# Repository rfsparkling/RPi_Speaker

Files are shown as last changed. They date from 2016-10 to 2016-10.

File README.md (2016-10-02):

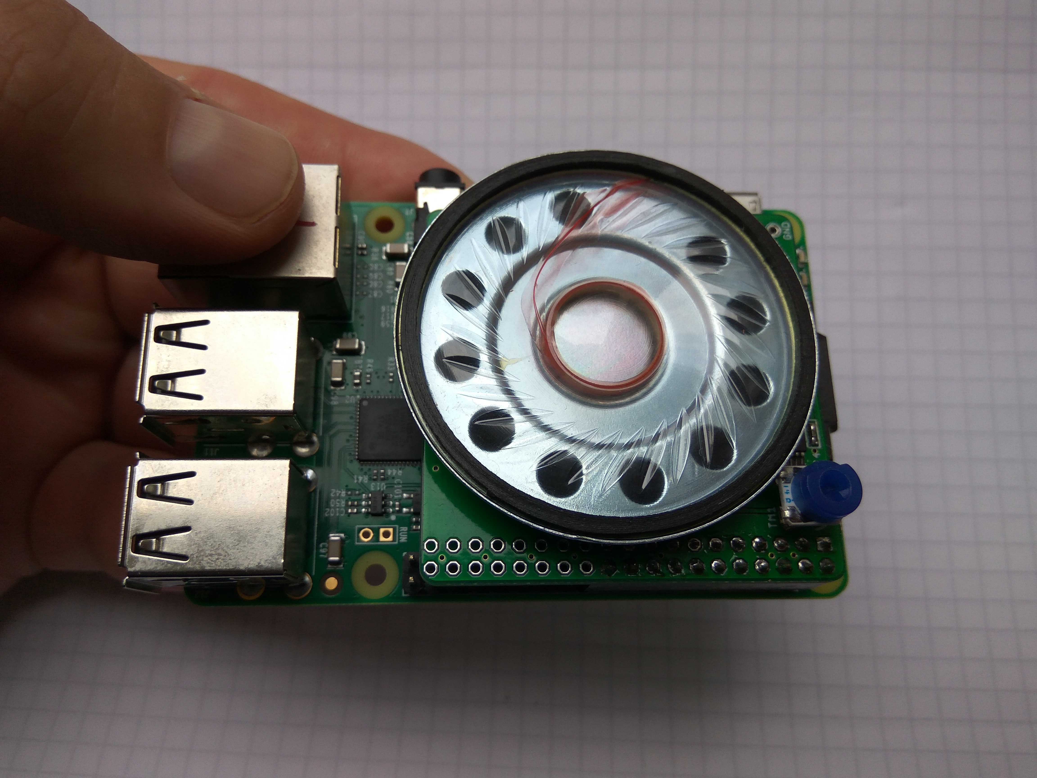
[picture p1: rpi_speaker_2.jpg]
Photo of RPi Speaker

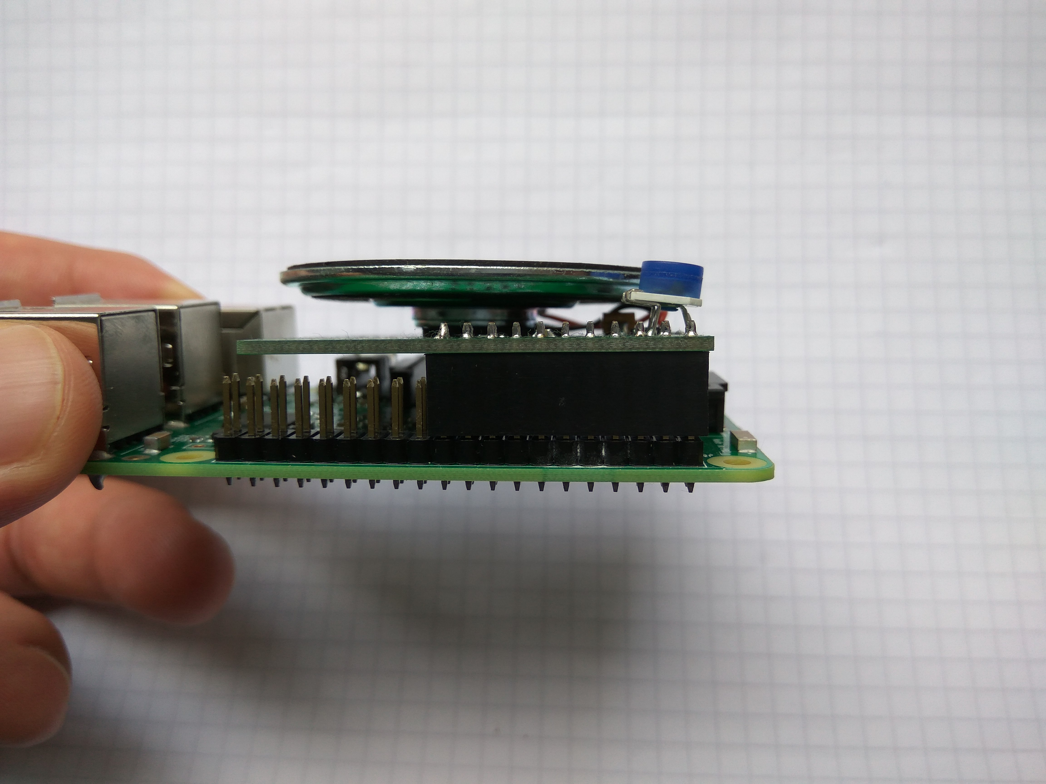
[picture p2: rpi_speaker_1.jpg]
Photo of RPi Speaker


Integrated active amplifier PCB for Rapsberry Pi (versions 1,2 and 3). On board LM386 amplifier do the amplification of the weak PWM audio signal coming out of RPi GPIO.
Also an on board low pass filter helps reconsturging the analog audio signal from PWM. 

Amplifier board built, find test video on Youtube here: http://bit.ly/rpi_speaker

------------
Installation
------------

Latest Raspbian OS has Pigpio software pre-installed, this handles GPIO alternative function. 
So just strart it and configure GPIO18 into ALT5 mode in RPi 2 and 3 (routing audio PWM signal to amplifier PCB):
In RPi 1 PWM audio can acces at GPIO12 port, see schematic.

Commands:

```
sudo pigpiod # start daemon
pigs m 18 5 # set GPIO18 to mode ALT5, RPi 2 and RPi 3 
```

Playing music with for example omxplayer (included in Raspbian) take care to route audio signal to PWM port and not HDMI output (-o local switch below).
You can listen internet stream or offline audio files. This example starts a music station:

```
omxplayer -o local http://bbcmedia.ic.llnwd.net/stream/bbcmedia_6music_mf_p
```

-----------------------
Alternative GPIO config
-----------------------

If Pigpio doesn't work for you, try this method:

https://www.raspberrypi.org/forums/viewtopic.php?f=44&t=39138

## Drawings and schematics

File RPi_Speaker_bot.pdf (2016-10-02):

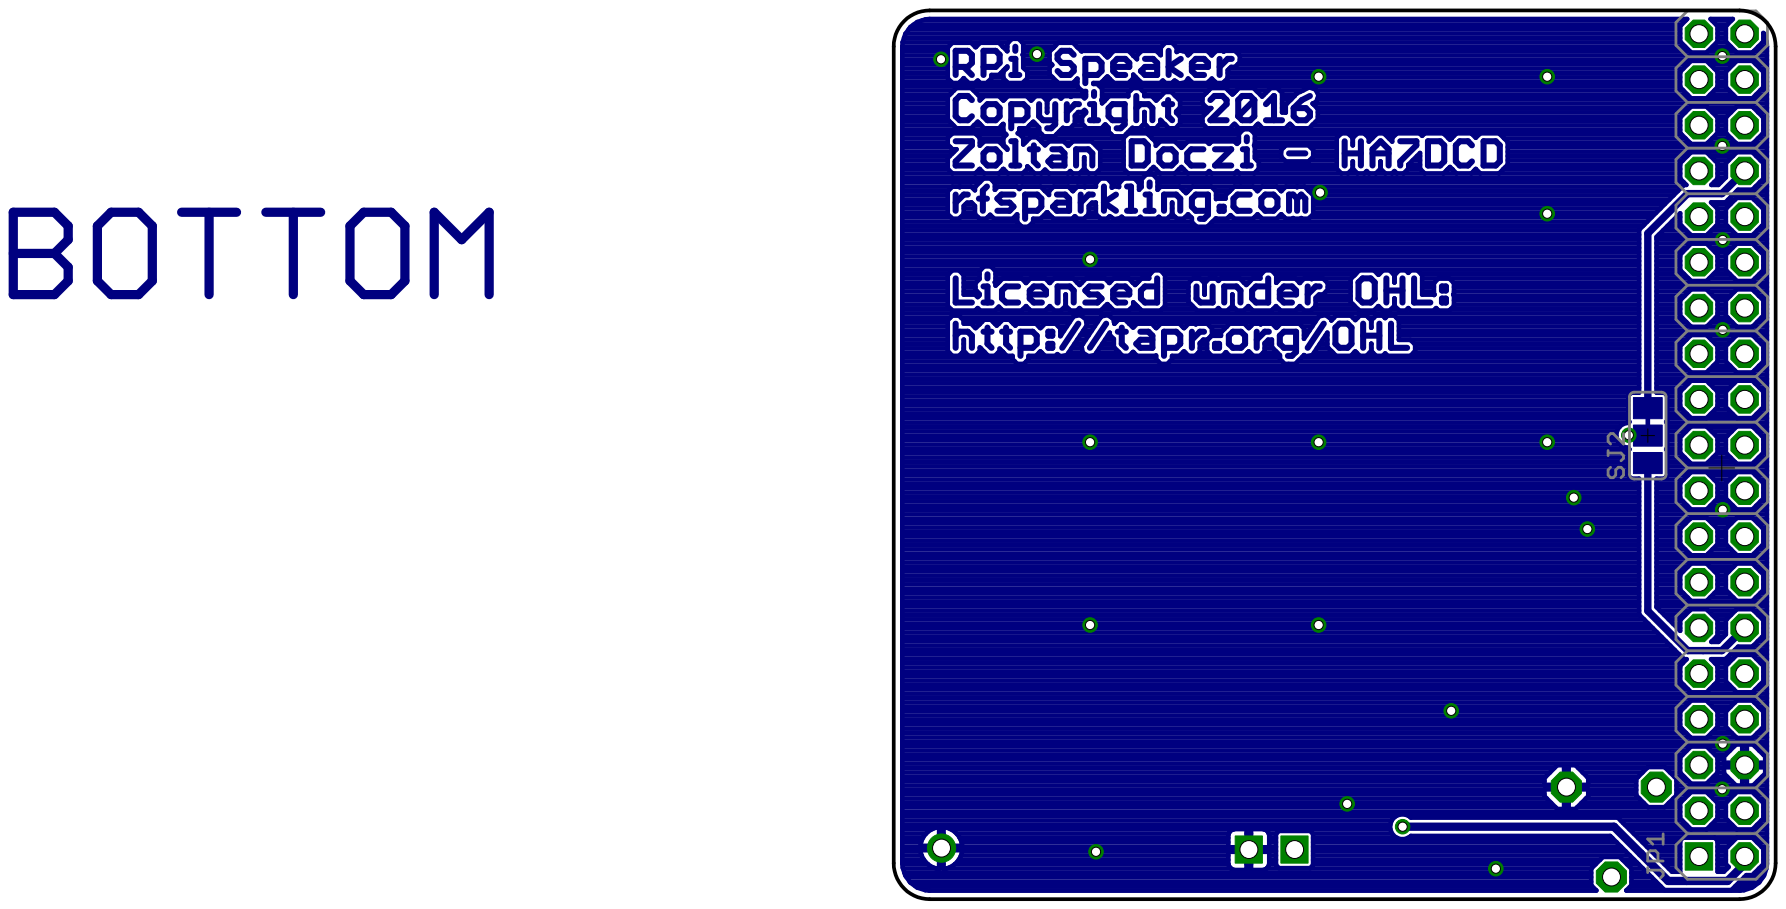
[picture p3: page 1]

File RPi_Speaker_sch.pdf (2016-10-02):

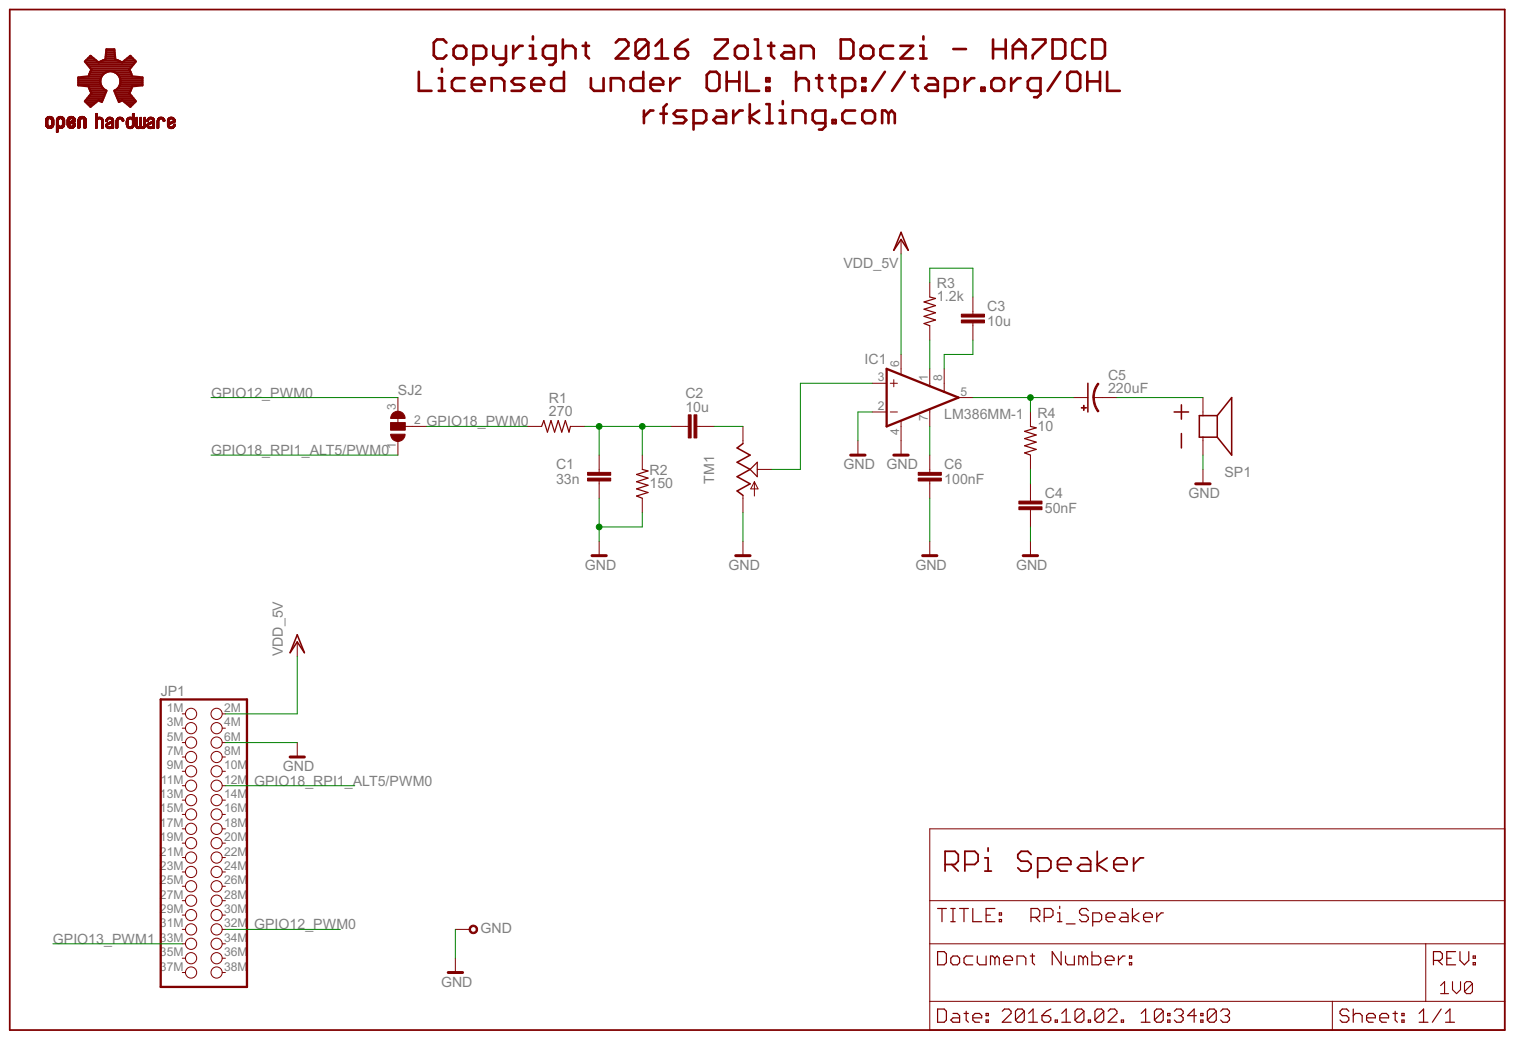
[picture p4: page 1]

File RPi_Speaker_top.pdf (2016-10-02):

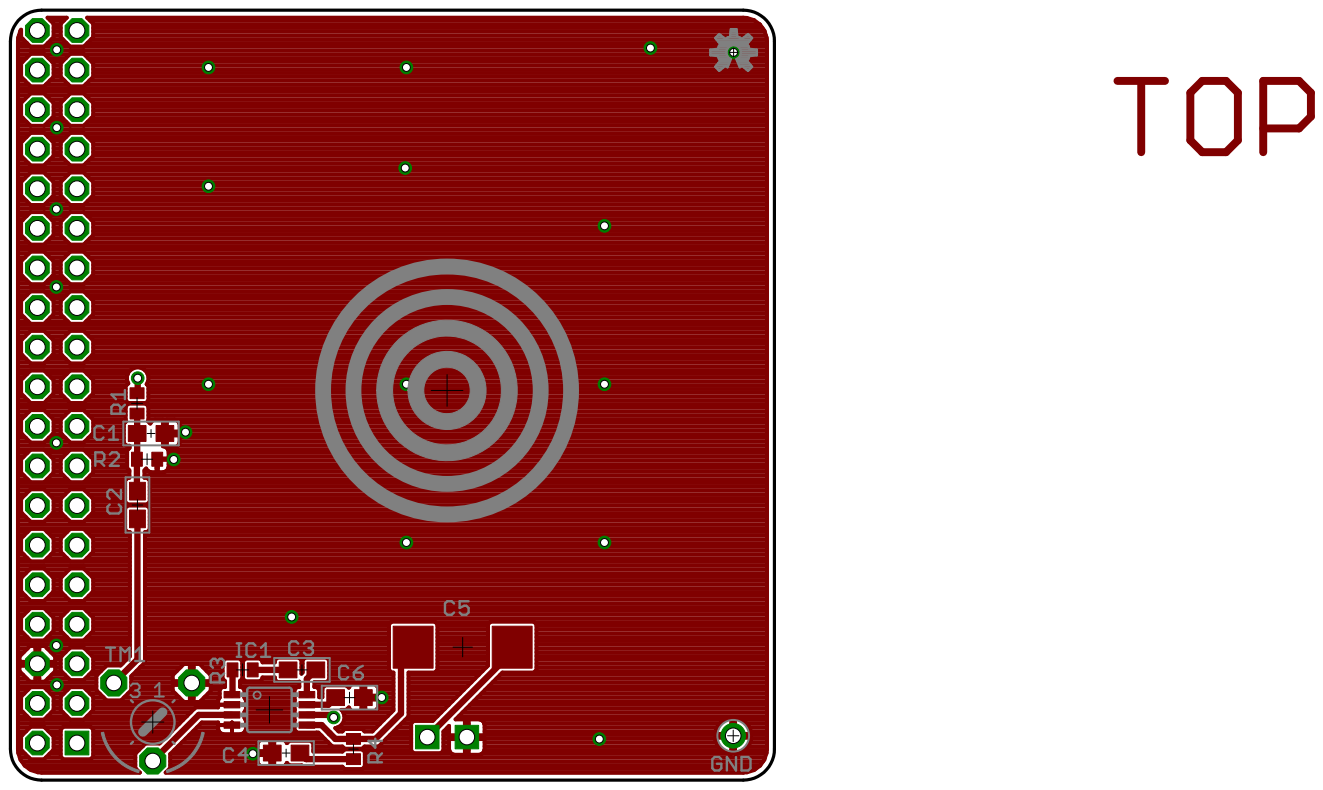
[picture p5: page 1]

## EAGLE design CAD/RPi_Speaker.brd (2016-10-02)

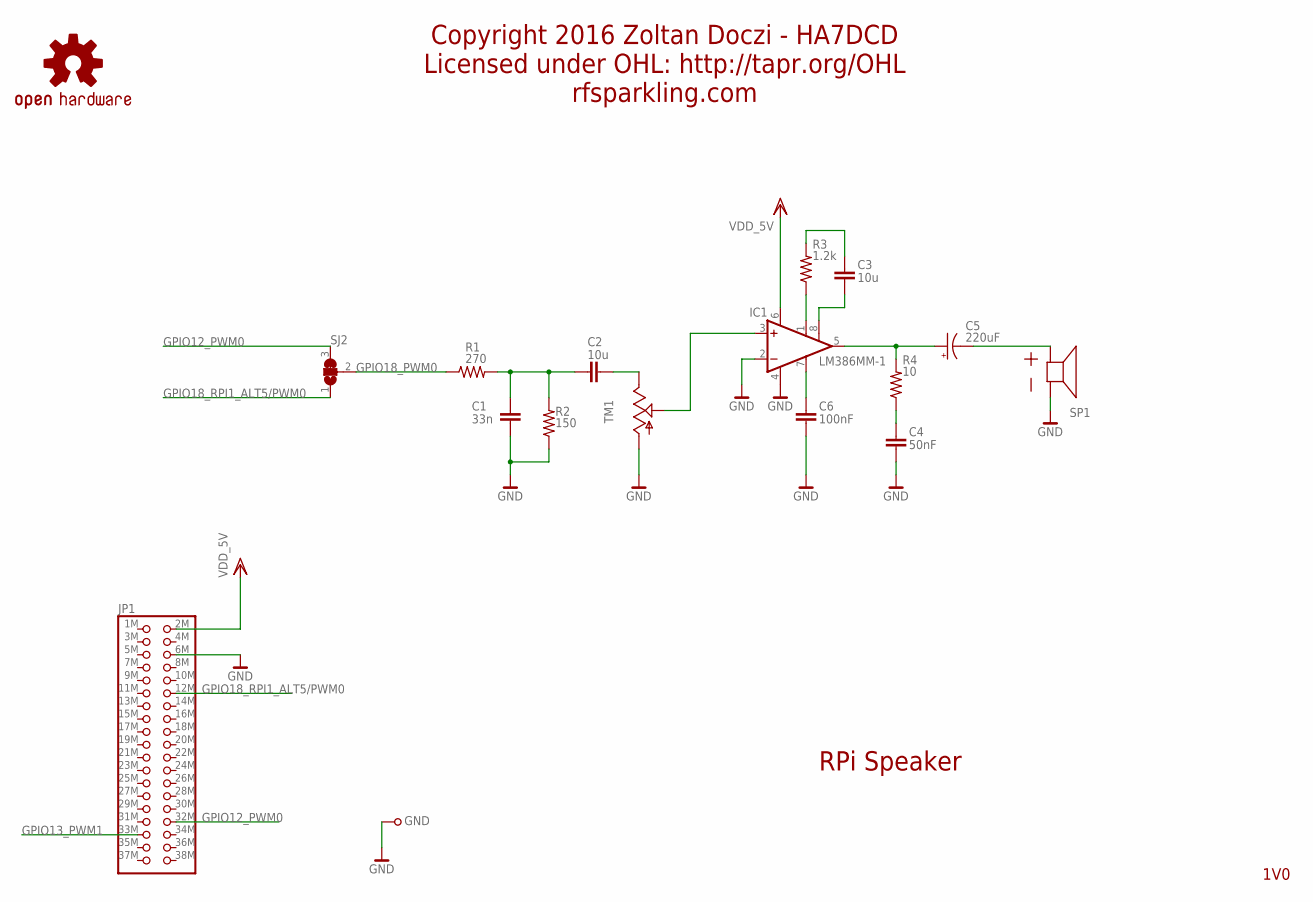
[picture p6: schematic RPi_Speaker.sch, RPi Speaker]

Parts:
C1: 33n; 0603
C2, C3: 10u; 0603
C4: 50nF; 0603
C5: 220uF; D/7343-31R
C6: 100nF; 0603
GND: TESTPOINT39MIL; TESTPOINT1,0
IC1: LM386MM-1; MMSOP08
JP1: PINHD-2X18/MIRROR; 2X18_MIRROR
R1: 270; R0402
R2: 150; R0402
R3: 1.2k; R0402
R4: 10; R0402
SJ2: JUMPER_SMD_3A; JUMPER_SMD_SJ2A
SP1: SPEAKER_ABS-210-RC; SPEAKER_ABS-210-RC_50MM
TM1: TRIM; 6MM
U$15: OSHW-LOGOS; OSHW-LOGO-S

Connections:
GND: C1.1, C4.2, C6.2, GND.1, IC1.2 (-IN), IC1.4 (GND), JP1.6M (6), R2.1, SP1.N (-), TM1.A
GPIO12_PWM0: JP1.32M (32), SJ2.3
GPIO13_PWM1: JP1.33M (33)
GPIO18_PWM0: R1.1, SJ2.2
GPIO18_RPI1_ALT5/PWM0: JP1.12M (12), SJ2.1
unnamed: C1.2, C2.2, R1.2, R2.2
unnamed: C2.1, TM1.E
unnamed: IC1.3 (+IN), TM1.S
unnamed: IC1.1 (GAIN), R3.1
unnamed: C3.1, R3.2
unnamed: C3.2, IC1.8 (GAIN)
unnamed: C5.+, IC1.5 (OUT), R4.2
unnamed: C4.1, R4.1
unnamed: C5.-, SP1.P (+)
unnamed: C6.1, IC1.7 (BYPASS)
VDD_5V: IC1.6 (VS), JP1.2M (2)

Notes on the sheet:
RPi Speaker
1V0
Copyright 2016 Zoltan Doczi - HA7DCD Licensed under OHL: http://tapr.org/OHL rfsparkling.com

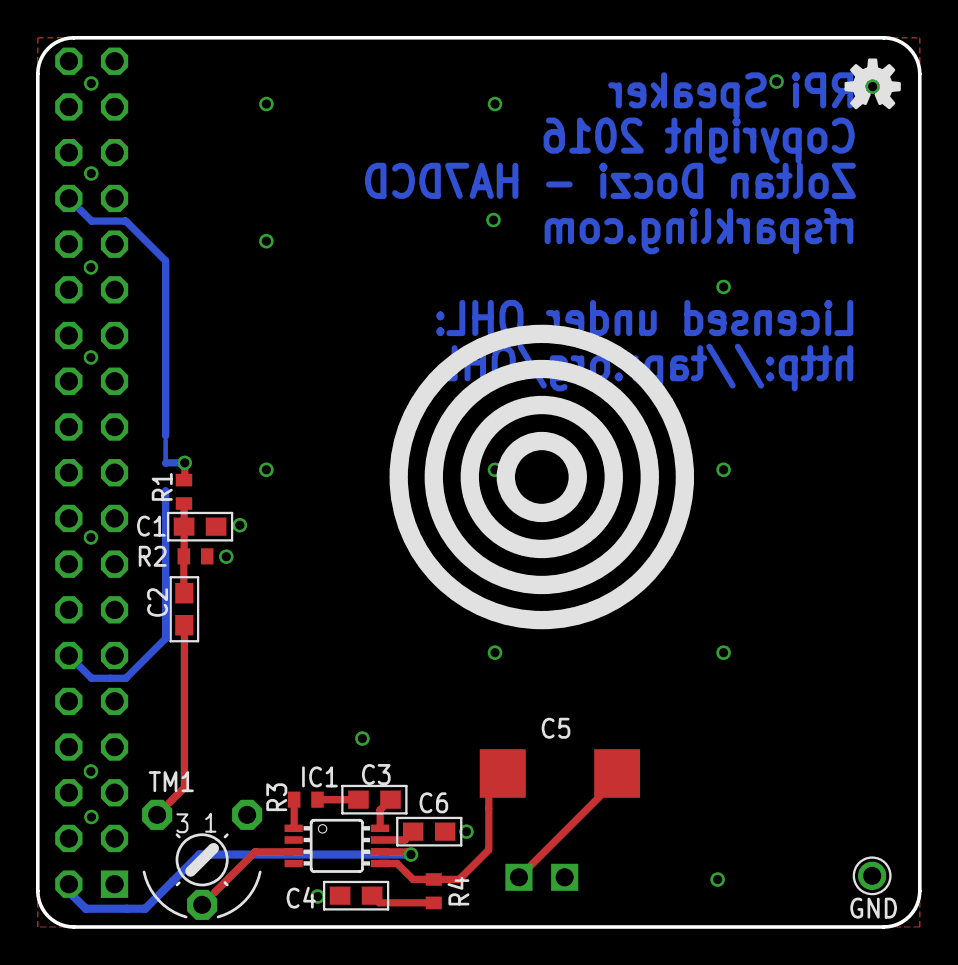
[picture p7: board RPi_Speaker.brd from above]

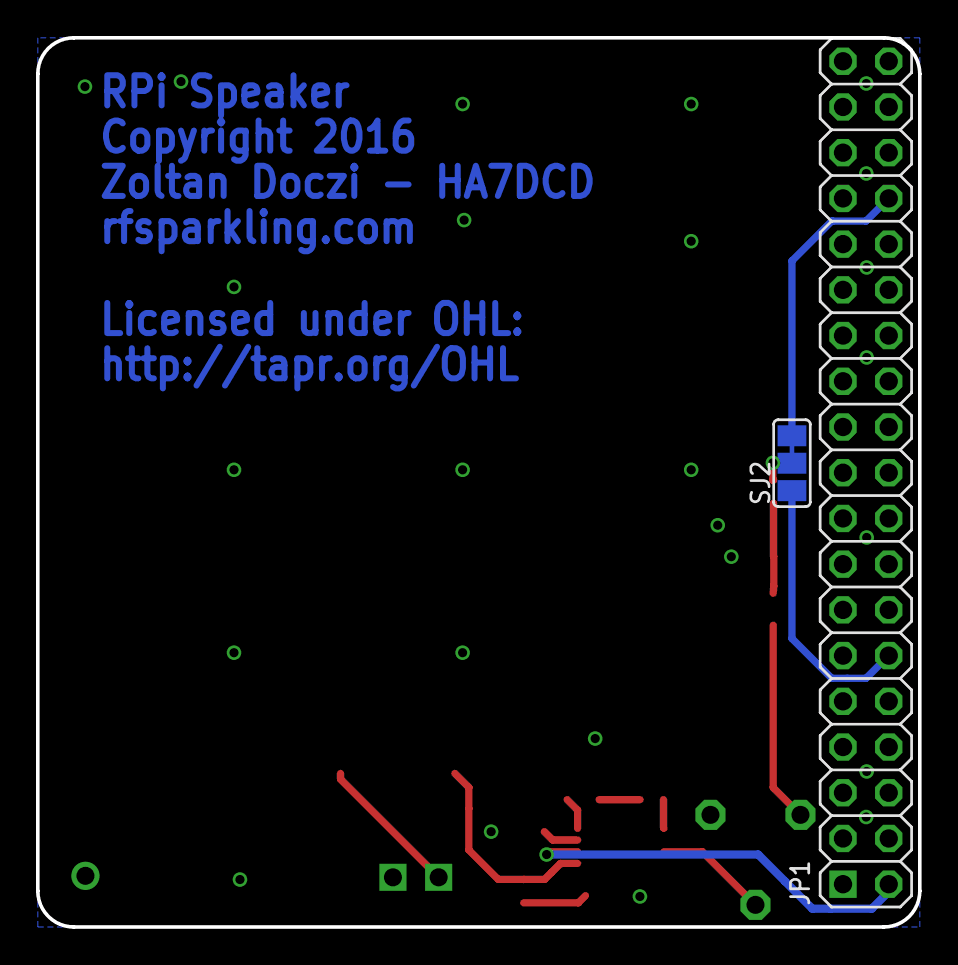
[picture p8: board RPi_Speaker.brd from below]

Board: 2 copper layers, 49.0 x 49.4 mm, 17 parts (2 on the bottom side), 15 nets.
